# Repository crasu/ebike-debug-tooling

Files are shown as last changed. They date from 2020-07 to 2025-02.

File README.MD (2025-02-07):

# Debug tooling for B* ebike system 2016 and later

## Overview

This debug tooling enables reading canbus information from the b* ebike system.

The tooling consists of the following parts:

1. Adapter for intercepting data from the Display connector port.
2. Platform.io project for an esp8266 to send the intercepted canbus frames to a smartphone/laptop via wifi. 
3. dbc file for dumping the received traces.

## How to use

### Adapter

1. 3D print the connector from the stl file in 'connector'
2. Cut a euroboard with stripe pattern to the required size.
3. Get some 2mmx9.5mm Pogo pins. Solder them to the board and use a lot of solder to create contact points for the pins coming from the display. 
4. Wire everything up

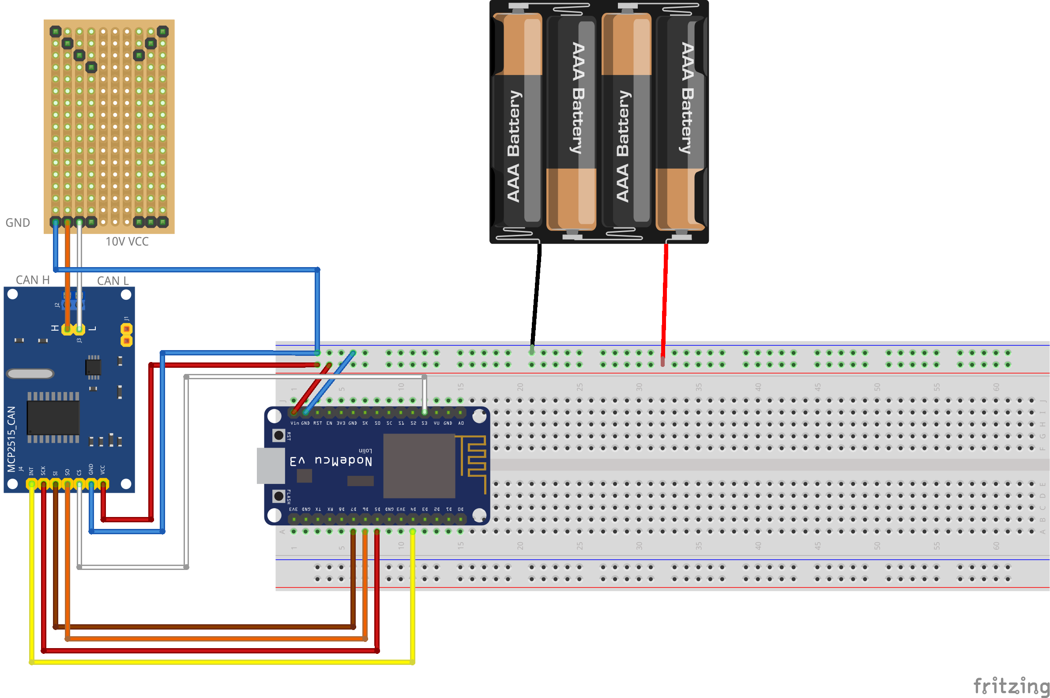
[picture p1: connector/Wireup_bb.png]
Wiring


#### Links

[euroboard](https://www.amazon.de/Euro-Platine-160x100-mm-Lochrasterplatine-Kupfer/dp/B002NL5YQY)
[pogo pins](https://www.amazon.de/gp/product/B07FPCPX8X/ref=ppx_yo_dt_b_search_asin_title?ie=UTF8&psc=1)

### ESP8266 Firmware

1. Adapt the wlan SSID and Key in `esp8266/src/settings.h.sample`
2. Rename `esp8266/src/settings.h.sample` to `esp8266/src/settings.h`
3. Compile the esp8266 firmware with pio and flash it to an esp8266
4. Attach a cheap MCP2515 transiver to the esp8266. (See picture)
5. Power the esp8266 via a usb power supply
6. Connect to the esp8266 via wifi on port 5001

    nc <esp_ip> 5001

7. You should now see received canbus frames 

### Dumping frames

1. Install can tool via `pipenv install` in `tracereader`
2. Enter venv shell via `pipenv shell`

     cat dumpfile | cantools decode -s drive.dbc

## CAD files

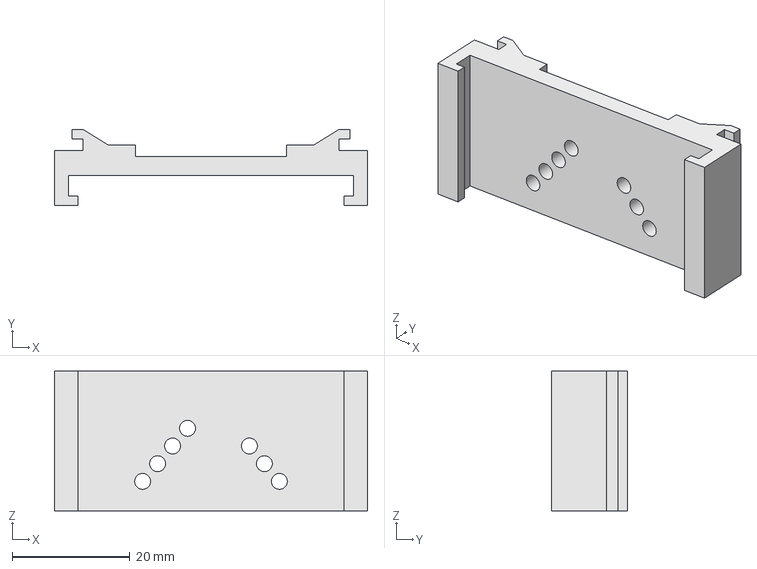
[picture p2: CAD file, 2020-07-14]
connector/Connector.fcstd
53.1 x 12.9 x 23.7 mm

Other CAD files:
connector/Connector.stl

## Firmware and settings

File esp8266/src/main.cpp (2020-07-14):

#include <Arduino.h>
#include <mcp_can.h>
#include <SPI.h>
#include <settings.h>
#include <ESP8266WiFi.h>

long unsigned int rxId;
unsigned char len;
unsigned char rxBuf[8];

char msgString[128];

#define CAN0_INT 2                              // Set INT to pin 2
MCP_CAN CAN0(10);                               // Set CS to pin 10

WiFiServer wifiServer(5001);

void setupWifi() {
  delay(500);
  WiFi.begin(WLAN_SSID, WLAN_SECRET);
 
  while (WiFi.status() != WL_CONNECTED) {
    delay(1000);
    Serial.println(F("Connecting to WIFI.."));
  }
 
  Serial.print("Connected to WiFi. IP:");
  Serial.println(WiFi.localIP());
 
  wifiServer.begin();
}

void setupCan() {
  if(CAN0.begin(MCP_ANY, CAN_500KBPS, MCP_8MHZ) == CAN_OK)
    Serial.println("MCP2515 Initialized Successfully!");
  else
    Serial.println("Error Initializing MCP2515...");
  
  CAN0.setMode(MCP_NORMAL);

  pinMode(CAN0_INT, INPUT);
  
  Serial.println("MCP2515 Remote output ...");
}

void setup()
{
  Serial.begin(115200);
  setupWifi();
  setupCan();  
}

void handleCanMessages(WiFiClient& client) {
  if(!digitalRead(CAN0_INT)) 
  {
    CAN0.readMsgBuf(&rxId, &len, rxBuf);              
    if((rxId & 0x80000000) == 0x80000000)          
      sprintf(msgString, "can0 %.8lX [%1d]", (rxId & 0x1FFFFFFF), len);
    else
      sprintf(msgString, "can0 %.3lX [%1d]", rxId, len);
  
    client.print(msgString);
  
    if((rxId & 0x40000000) == 0x40000000){   
      sprintf(msgString, " REMOTE REQUEST FRAME");
      client.print(msgString);
    } else {
      for(byte i = 0; i<len; i++){
        sprintf(msgString, " %.2X", rxBuf[i]);
        client.print(msgString);
      }
    }
        
    client.println();
  }
}

void loop()
{
  WiFiClient client = wifiServer.available();
  if (client) {
    Serial.println("Client connected!");
    while (client.connected()) {
      handleCanMessages(client);
      yield();
    }
 
    client.stop();
    Serial.println("Client disconnected");
  }  
}

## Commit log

2020-07-14 initial version
    [Connector.fcstd, Connector.stl, Wireup.fzz]
2020-07-14 fixed spelling
    [Connector.fcstd, Connector.stl, Wireup.fzz]
